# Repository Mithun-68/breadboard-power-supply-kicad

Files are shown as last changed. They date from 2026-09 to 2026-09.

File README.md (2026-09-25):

## Project Overview
This project is an open-source, dual-rail breadboard power supply designed to plug directly into standard MB-102 breadboard power buses. Powered via a standard $7\text{V} - 12\text{V}$ DC barrel jack, it generates independent $3.3\text{V}$ and $5.0\text{V}$ linear-regulated rails to safely power microcontrollers, sensors, and prototype circuits.

| 3D PCB Render | Schematic Diagram |
| :---: | :---: |
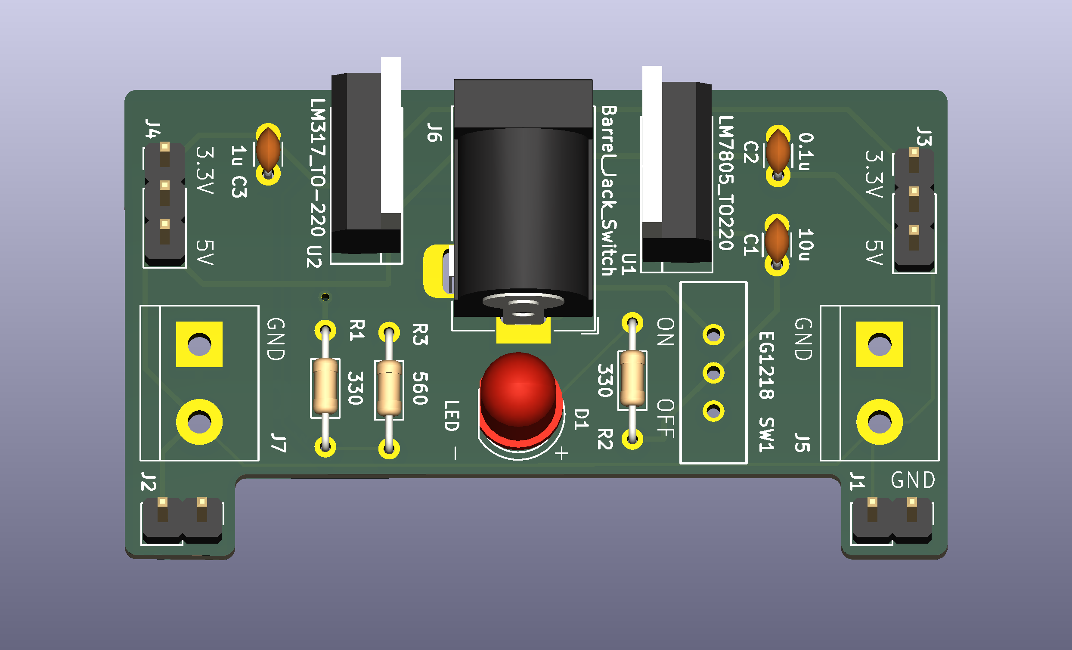
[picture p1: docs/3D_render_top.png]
3D PCB Render
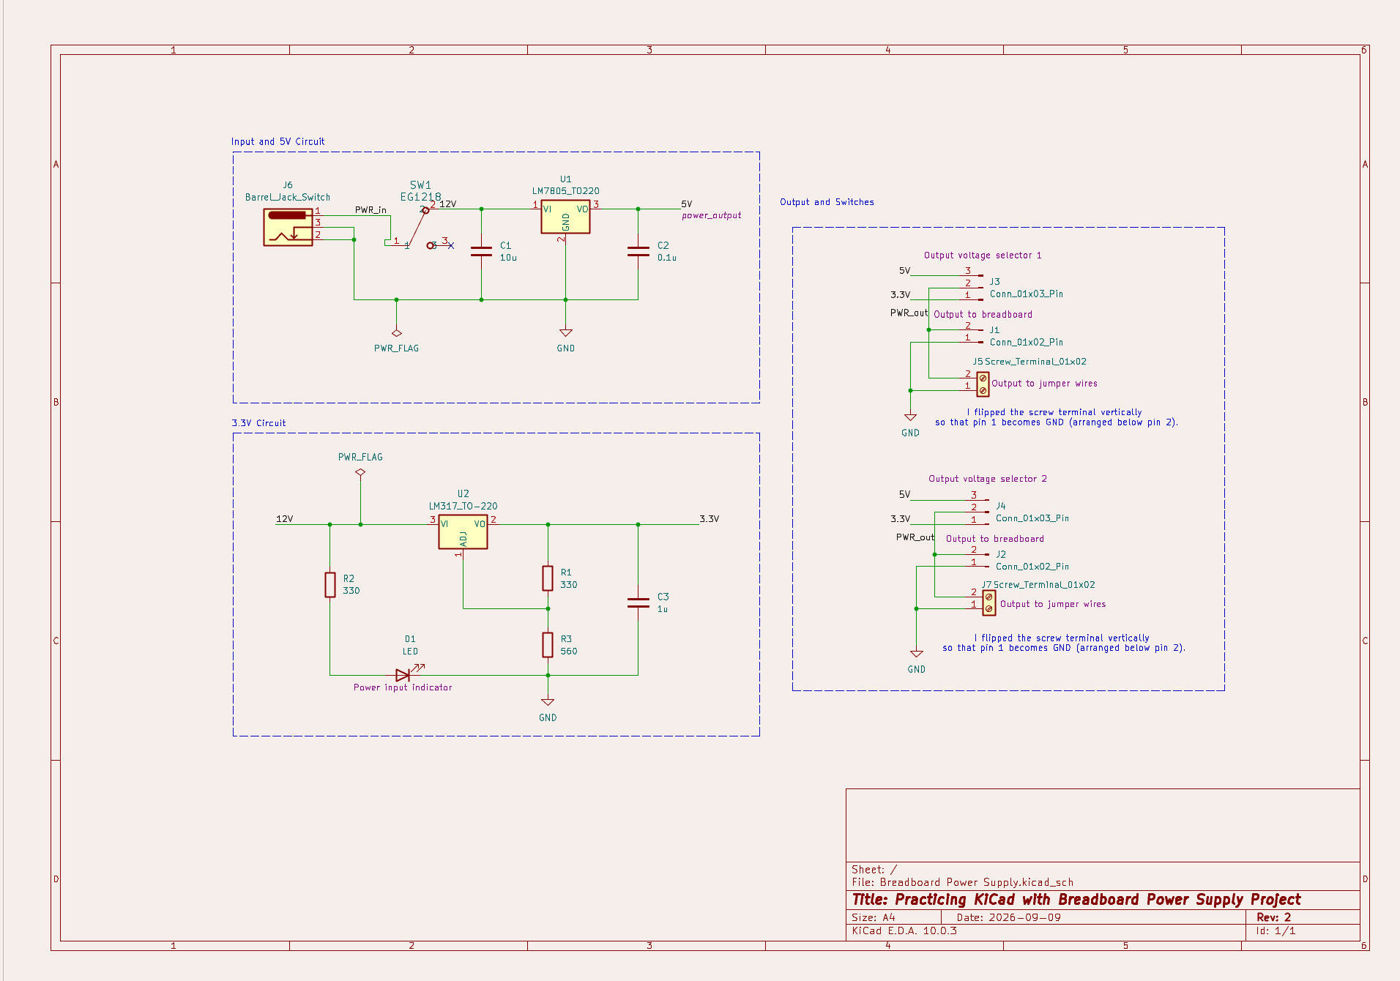
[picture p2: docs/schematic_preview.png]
Schematic Diagram
|  |  |

---

## Technical Specifications
* **Input Voltage:** $7\text{V} - 12\text{V}$ DC via $2.1\text{ mm} \times 5.5\text{ mm}$ Barrel Jack (`J6`)
* **Regulated Output Rails:** Dual selectable $3.3\text{V}$ and $5.0\text{V}$ outputs
* **Max Output Current:** Up to $800\text{mA}$ total (thermally limited)
* **Master Power Control:** Onboard SPDT slide switch (`SW1`) with power status LED (`D1`)
* **Output Selectors:** 3-pin headers (`J3` & `J4`) with physical jumper shunts to independently assign $3.3\text{V}$ or $5.0\text{V}$ to each breadboard rail
* **Auxiliary Outputs:** 2-pin screw terminals (`J5` & `J7`) wired in parallel for multimeter leads or external wiring
* **Form Factor:** Standard $2.54\text{ mm}$ pitch headers for MB-102 breadboard dual-bus alignment
  
## KiCad Layout & Hardware Design Highlights
* **Ground Plane Pour:** Large top and bottom copper pours (`F.Cu` and `B.Cu`) act as a solid ground reference and help dissipate thermal energy generated by the linear regulators.
* **Filter & Decoupling Capacitors:** Bulk $10\ \mu\text{F}$ input capacitance suppresses low-frequency DC ripple, while dedicated $0.1\ \mu\text{F}$ and $1\ \mu\text{F}$ ceramic capacitors placed close to regulator outputs eliminate high-frequency noise and voltage dip transients.
* **LM317 Voltage Setting:** Configured with a precision resistor feedback divider ($R_1 = 330\ \Omega$, $R_3 = 560\ \Omega$) to yield a stable $3.37\text{ V}$ nominal rail.
* **Thermal Reliefs & Manufacturing Rules:** Applied spoke thermal reliefs on ground pads for smooth hand-soldering. Fully DRC-verified against standard $6\text{ mil}$ clearance and trace width rules for instant fabrication via JLCPCB or PCBWay.

## Project Origin & Attribution
I designed this as a practical portfolio project following the structured learning modules in **"PCB Design with KiCad"** by Dr. Peter Dalmaris. I independently executed all schematic capture, PCB routing, ground pour strategy, DRC verification, and fabrication output generation in KiCad 10.

## Repository Organization
```text
├── README.md                 # Project overview & design documentation
├── .gitignore                # KiCad temporary & cache file filters
├── docs/                     # Visual assets (3D renders, schematic PDF)
├── hardware/                 # KiCad 10 source files (.kicad_sch, .kicad_pcb)
└── production/               # Fabrication deliverables
    ├── gerbers/               # Zipped Gerber manufacturing archive (.zip)
    ├── bom/                  # Component lists (CSV & Interactive HTML BOM)
    └── assembly/             # Pick-and-place files (.pos / pdf)

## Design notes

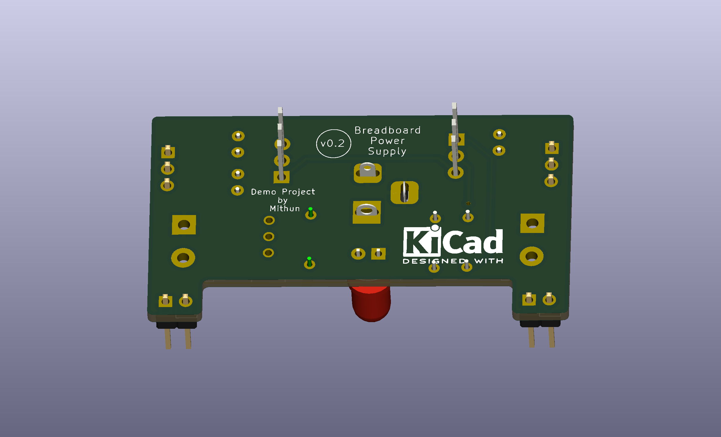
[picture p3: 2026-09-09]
docs/3D_render_bottom.png

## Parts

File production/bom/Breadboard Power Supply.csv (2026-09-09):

Id | Designator | Footprint | Quantity | Designation | Supplier and ref
1 | C1 | C_Disc_D3.0mm_W1.6mm_P2.50mm | 1 | 10u
2 | C2 | C_Disc_D3.0mm_W1.6mm_P2.50mm | 1 | 0.1u
3 | C3 | C_Disc_D3.0mm_W1.6mm_P2.50mm | 1 | 1u
4 | D1 | LED_D5.0mm | 1 | LED
5 | J1, J2 | PinHeader_1x02_P2.54mm_Vertical | 2 | Conn_01x02_Pin
6 | J3, J4 | PinHeader_1x03_P2.54mm_Vertical | 2 | Conn_01x03_Pin
7 | J5, J7 | TerminalBlock_bornier-2_P5.08mm | 2 | Screw_Terminal_01x02
8 | J6 | BarrelJack_Horizontal | 1 | Barrel_Jack_Switch
9 | R1, R2 | R_Axial_DIN0204_L3.6mm_D1.6mm_P7.62mm_Horizontal | 2 | 330
10 | R3 | R_Axial_DIN0204_L3.6mm_D1.6mm_P7.62mm_Horizontal | 1 | 560
11 | SW1 | SW_1218_EWI | 1 | EG1218
12 | U1 | TO-220-3_Vertical | 1 | LM7805_TO220
13 | U2 | TO-220-3_Vertical | 1 | LM317_TO-220

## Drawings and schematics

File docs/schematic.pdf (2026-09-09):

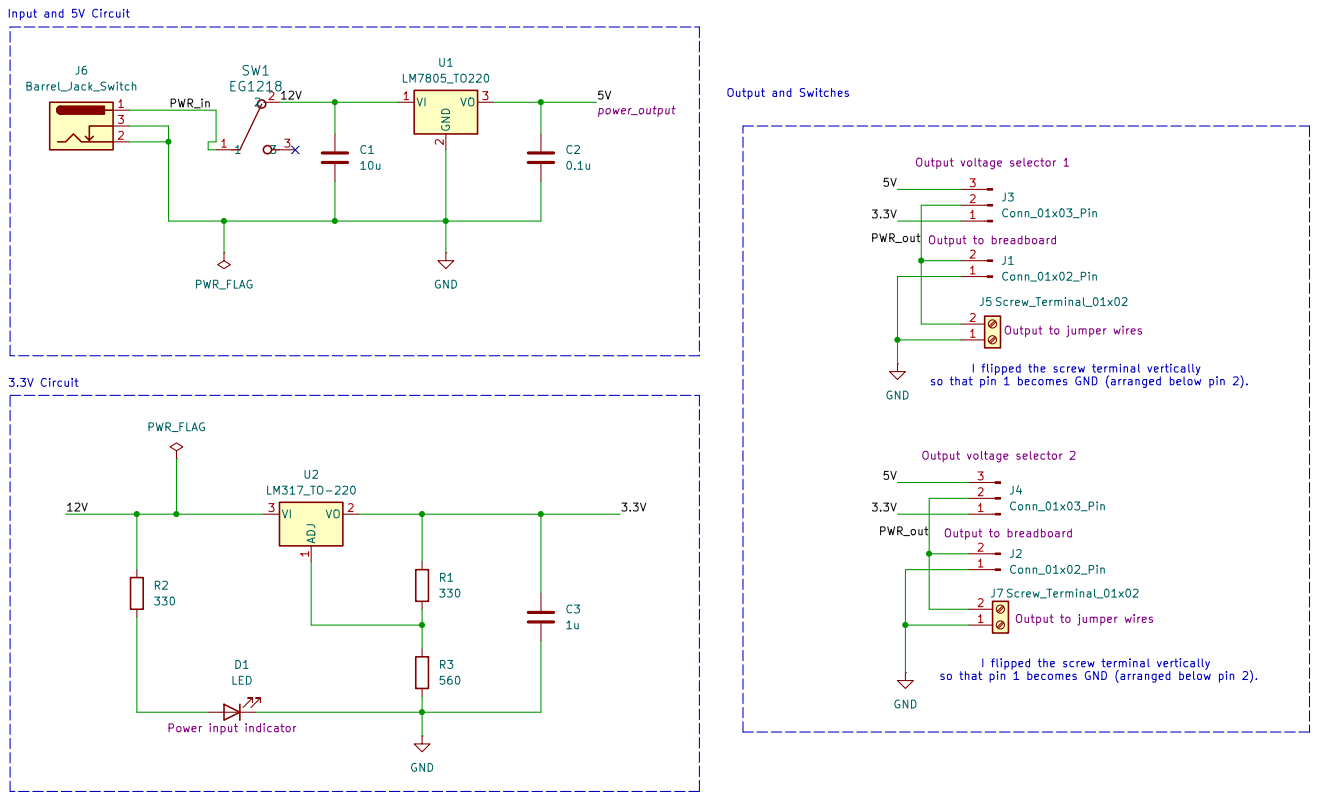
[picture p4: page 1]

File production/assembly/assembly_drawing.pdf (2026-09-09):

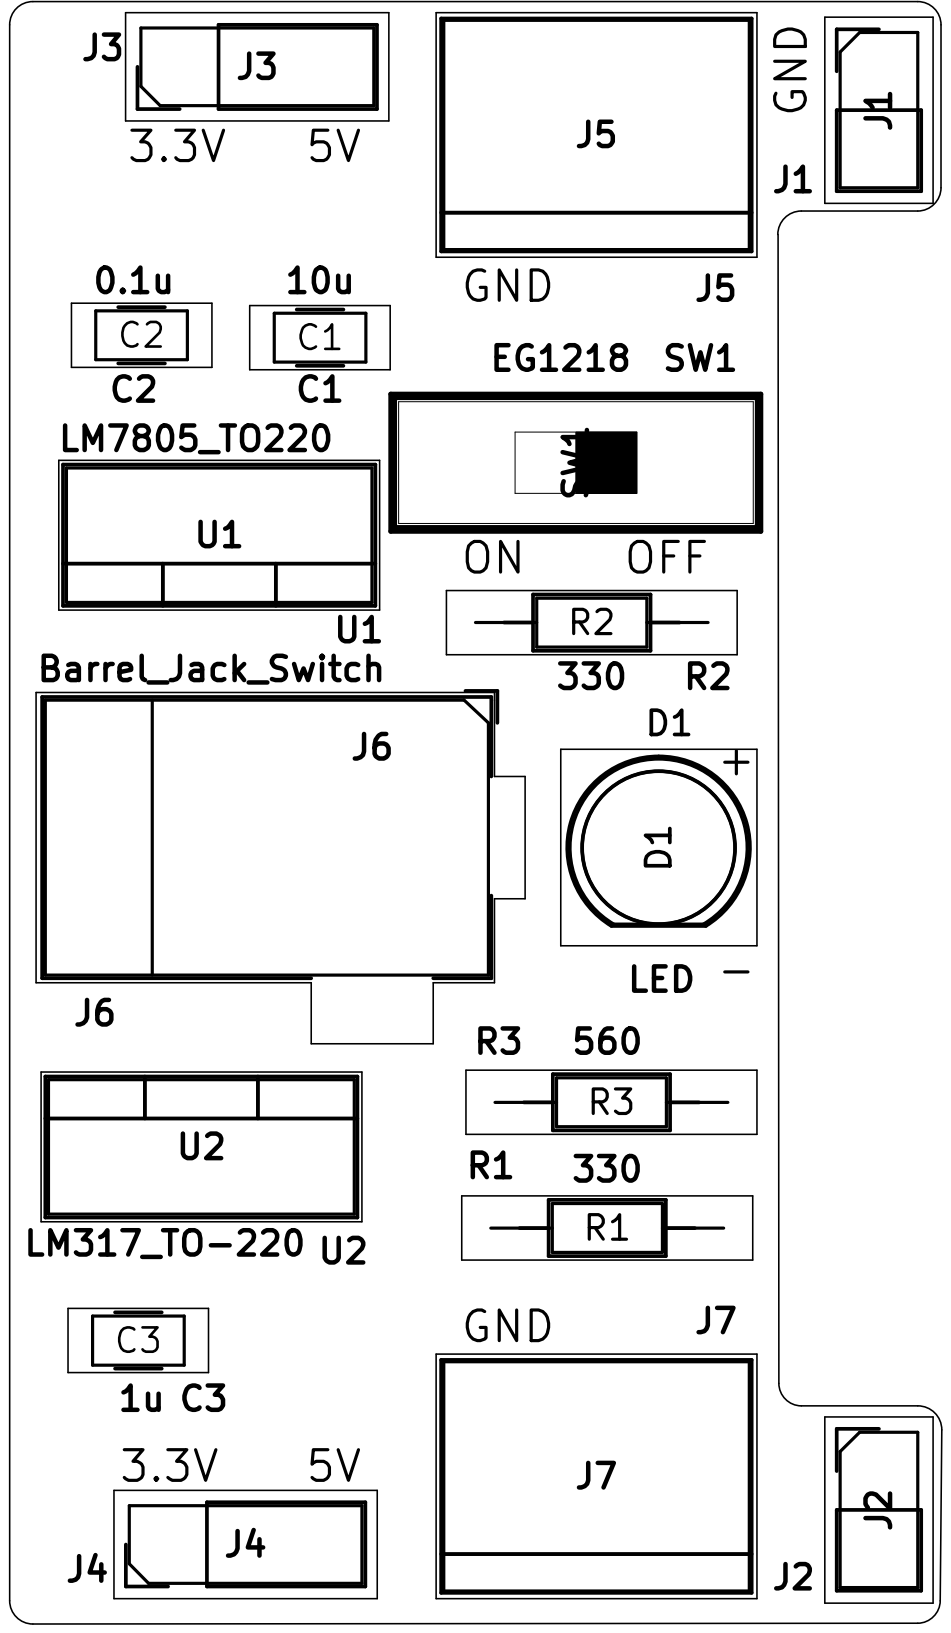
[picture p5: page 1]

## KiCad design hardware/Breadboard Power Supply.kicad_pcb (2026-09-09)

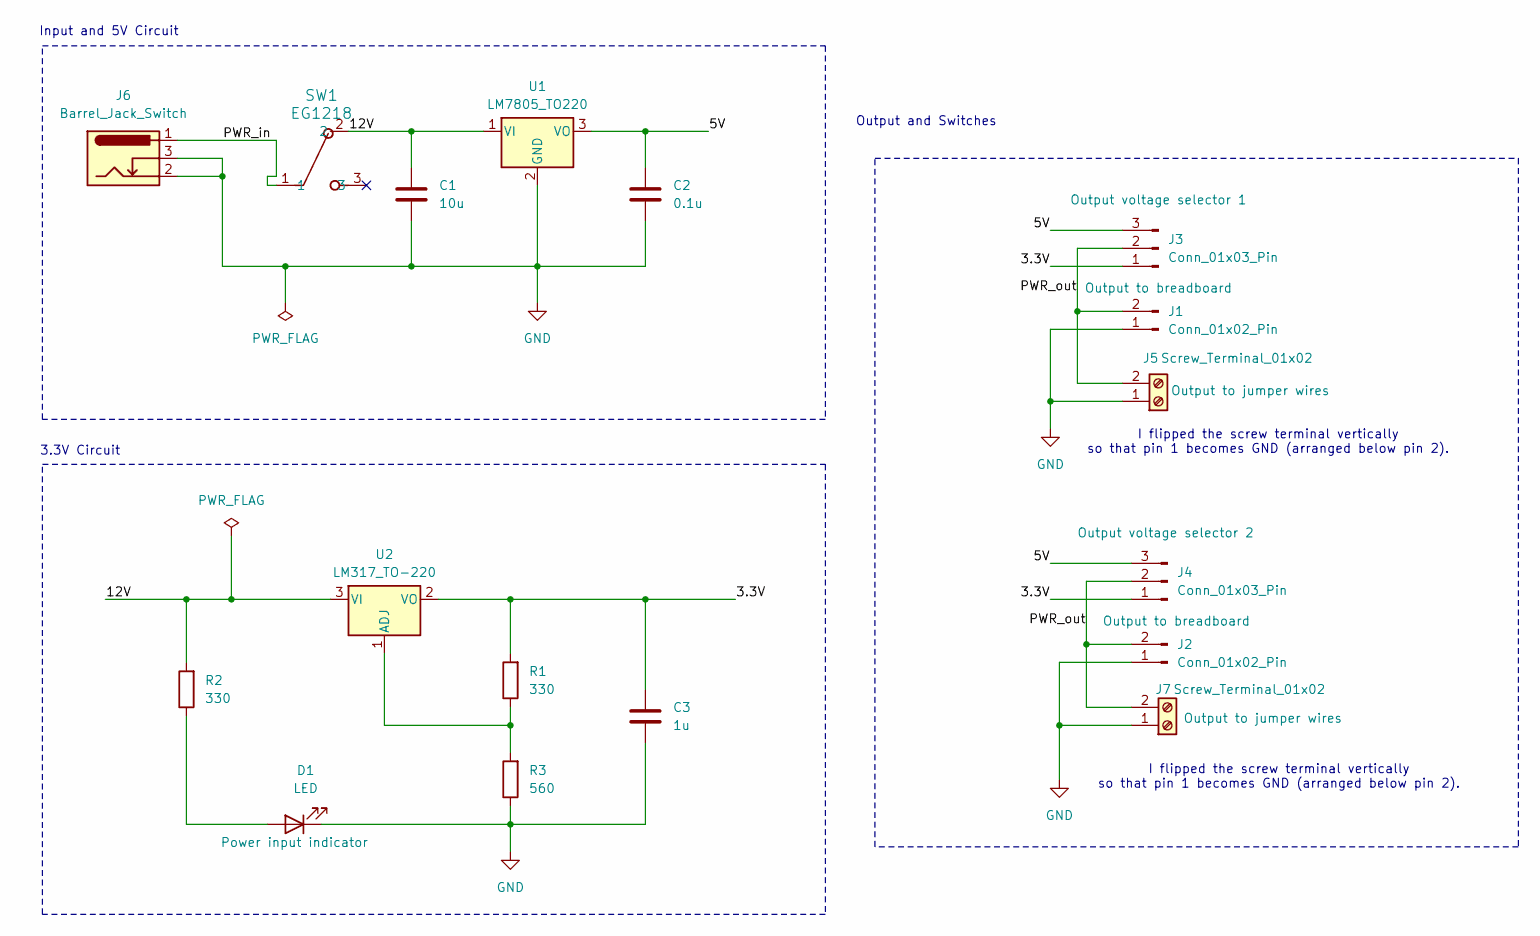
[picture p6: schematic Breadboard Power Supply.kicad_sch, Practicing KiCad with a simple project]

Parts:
C1: 10u; C_Disc_D3.0mm_W1.6mm_P2.50mm
C2: 0.1u; C_Disc_D3.0mm_W1.6mm_P2.50mm
C3: 1u; C_Disc_D3.0mm_W1.6mm_P2.50mm
D1: LED; LED_D5.0mm
J1, J2: Conn_01x02_Pin; PinHeader_1x02_P2.54mm_Vertical
J3, J4: Conn_01x03_Pin; PinHeader_1x03_P2.54mm_Vertical
J5, J7: Screw_Terminal_01x02; TerminalBlock_bornier-2_P5.08mm
J6: Barrel_Jack_Switch; BarrelJack_Horizontal
R1, R2: 330; R_Axial_DIN0204_L3.6mm_D1.6mm_P7.62mm_Horizontal
R3: 560; R_Axial_DIN0204_L3.6mm_D1.6mm_P7.62mm_Horizontal
SW1: EG1218; SW_1218_EWI
U1: LM7805_TO220; TO-220-3_Vertical
U2: LM317_TO-220; TO-220-3_Vertical

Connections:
/3.3V: C3.1, J3.1, J4.1, R1.2, U2.2 (VO)
/5V: C2.1, J3.3, J4.3, U1.3 (VO)
/12V: C1.1, R2.2, SW1.2, U1.1 (VI), U2.3 (VI)
/PWR_in: J6.1, SW1.1
/PWR_out: J1.2, J2.2, J3.2, J4.2, J5.2, J7.2
GND: C1.2, C2.2, C3.2, D1.1 (K), J1.1, J2.1, J5.1, J6.2, J6.3, J7.1, R3.1, U1.2 (GND)
unnamed: D1.2 (A), R2.1
unnamed: R1.1, R3.2, U2.1 (ADJ)

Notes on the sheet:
3.3V Circuit
I flipped the screw terminal vertically so that pin 1 becomes GND (arranged below pin 2).
Input and 5V Circuit
Output and Switches

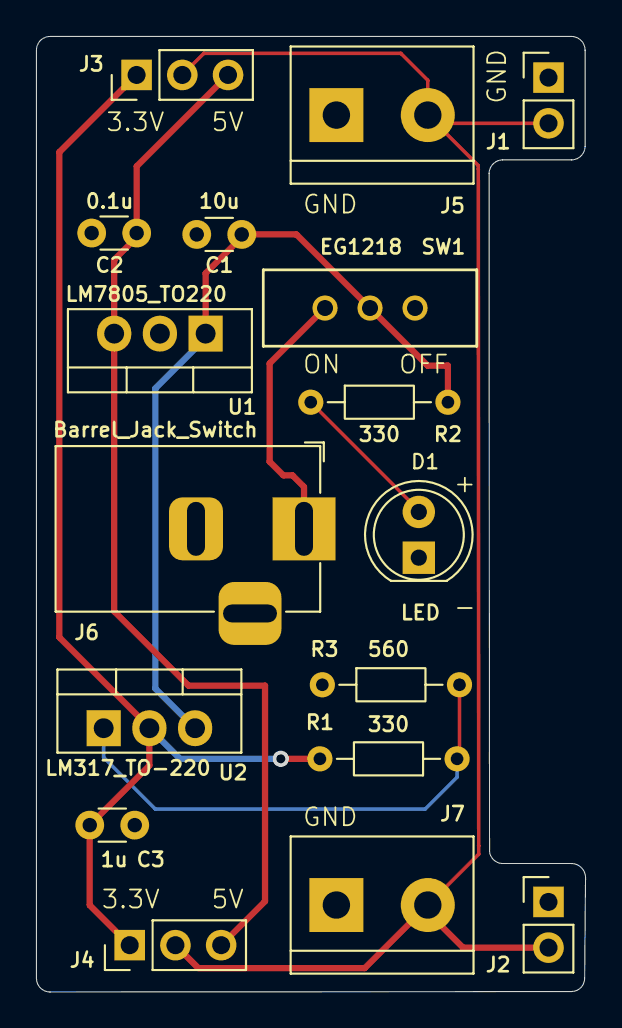
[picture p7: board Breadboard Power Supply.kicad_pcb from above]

Board: 2 copper layers, 30.5 x 53.1 mm, 17 parts (0 on the bottom side), 8 nets.
